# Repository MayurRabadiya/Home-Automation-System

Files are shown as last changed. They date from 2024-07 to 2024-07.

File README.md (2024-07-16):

# Home Automation System
## What is Home Automation?
Home automation, often referred to as smart home technology, involves the automation of household activities through various control systems. This includes the monitoring and control of home attributes such as lighting, climate, entertainment systems, and appliances. Additionally, home automation encompasses security features like access control and alarm systems. When connected to the Internet, these devices become integral components of the Internet of Things (IoT).

## Project Aim
The objective of our Smart Module is to provide a comprehensive solution for controlling home electronic appliances using a smartphone, touch control, IR remote, and voice assistants like Alexa and Google Assistant.

## Modes of Operation
1. Touch Control: Utilizes a Cypress capacitive touch sensor to detect user touch inputs and respond based on the previous state of the relay.

2. Voice Command: Voice commands are facilitated through Alexa, which publishes MQTT messages. The ESP8266 module subscribes to these topics to receive the messages. Communication between the Cypress chip and ESP8266 occurs via I2C, enabling the system to react appropriately.

3. IR Remote: The ESP8266 decodes input from an IR remote and sends commands to the Cypress chip via I2C communication. The Cypress chip processes these commands to control the relays.

4. Smartphone: A smartphone app publishes MQTT messages that the ESP8266 module subscribes to. These messages are communicated to the Cypress chip through I2C, enabling the system to control the relays based on the received commands.

This project demonstrates the integration of various modern technologies to create a versatile and user-friendly home automation system.

## Images
Touch pad top side           |  Touch pad bottom side
:-------------------------:|:-------------------------:
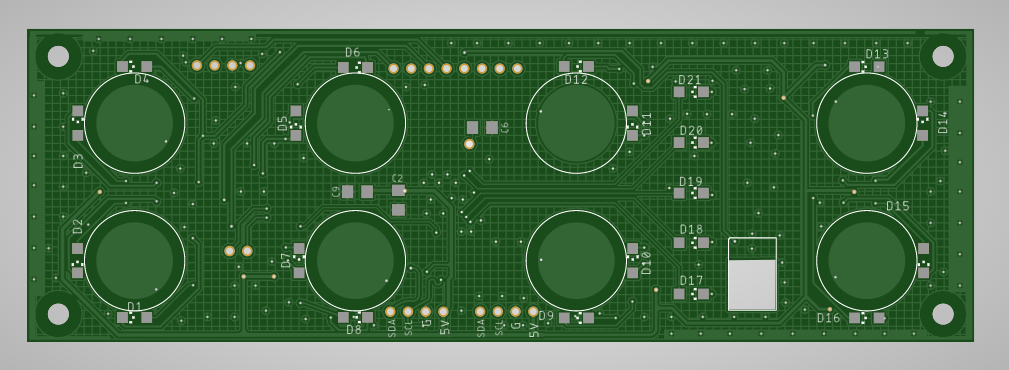
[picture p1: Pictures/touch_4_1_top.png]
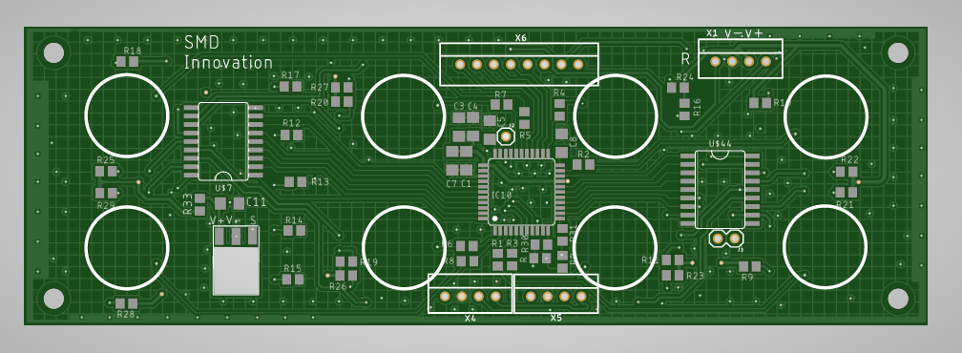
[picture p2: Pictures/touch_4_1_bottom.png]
  |  

Power base top side           |  Power base bottom side
:-------------------------:|:-------------------------:
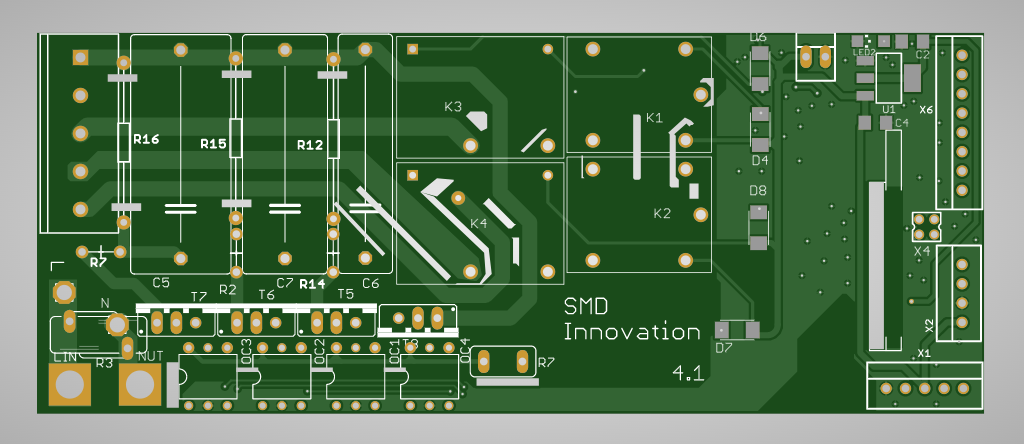
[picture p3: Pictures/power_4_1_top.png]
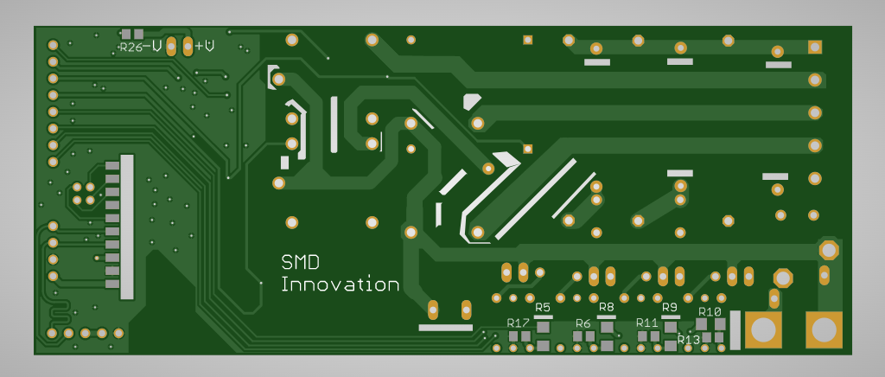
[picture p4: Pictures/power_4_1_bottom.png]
  |  

Front Cover      
| :-------------------------:|
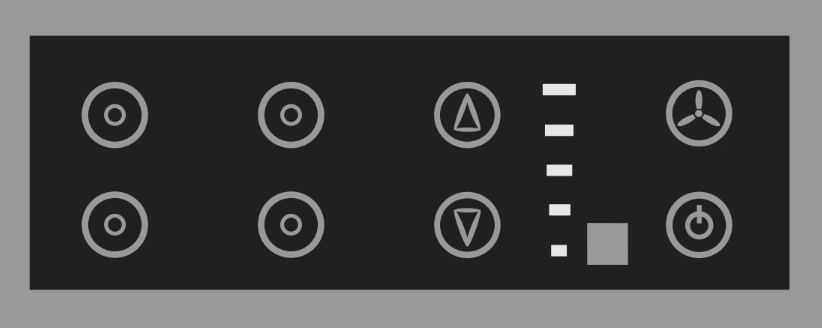
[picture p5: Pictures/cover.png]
|   |

Demo

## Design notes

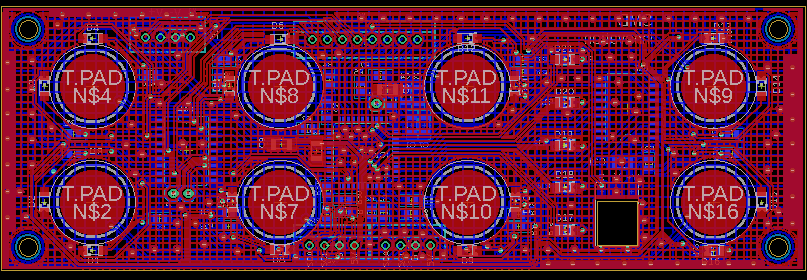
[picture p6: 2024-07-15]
4.1/4.1_TOUCH/pictures/4.1_top.png

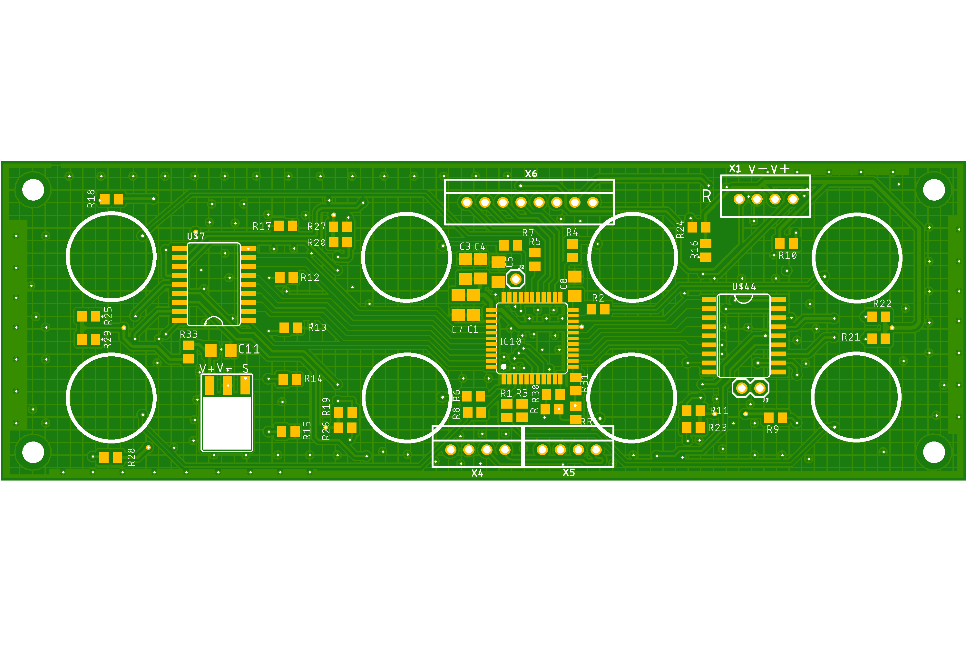
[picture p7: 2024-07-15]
4.1/4.1_TOUCH/pictures/6_light_1_fan_1.png

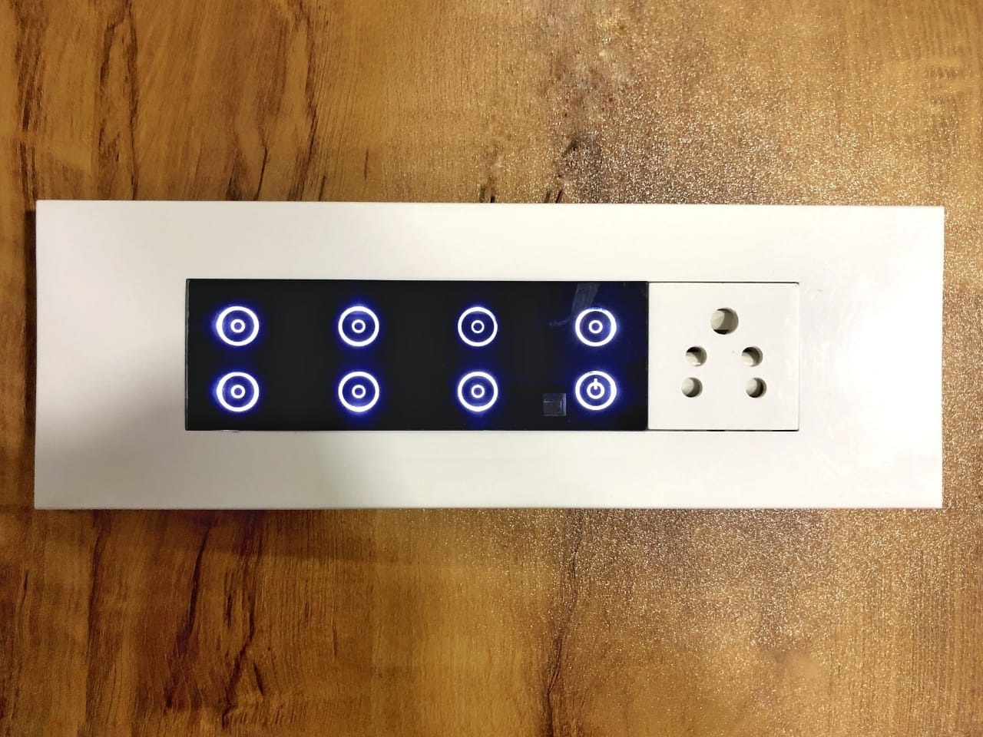
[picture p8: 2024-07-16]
Pictures/Touch Panel.png

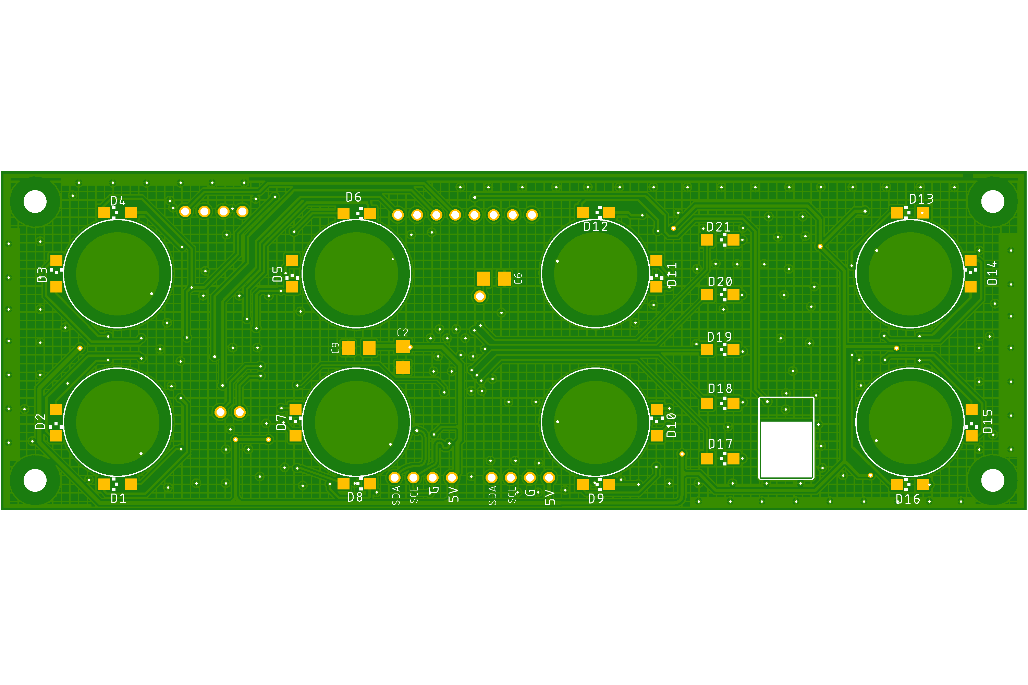
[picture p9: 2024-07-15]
4.1/4.1_TOUCH/pictures/6_light_1_fan_0.png

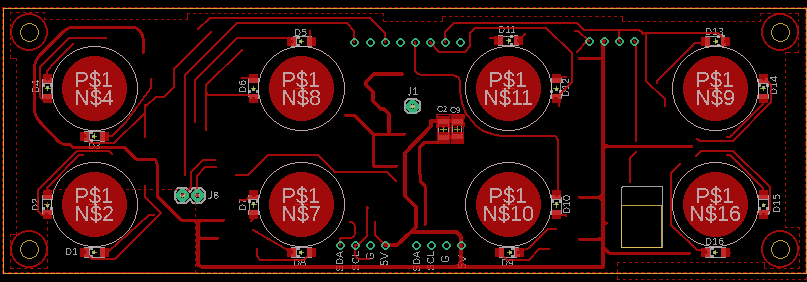
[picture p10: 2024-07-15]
7.0/7.0_TOUCH/pictures/7.0_top.png

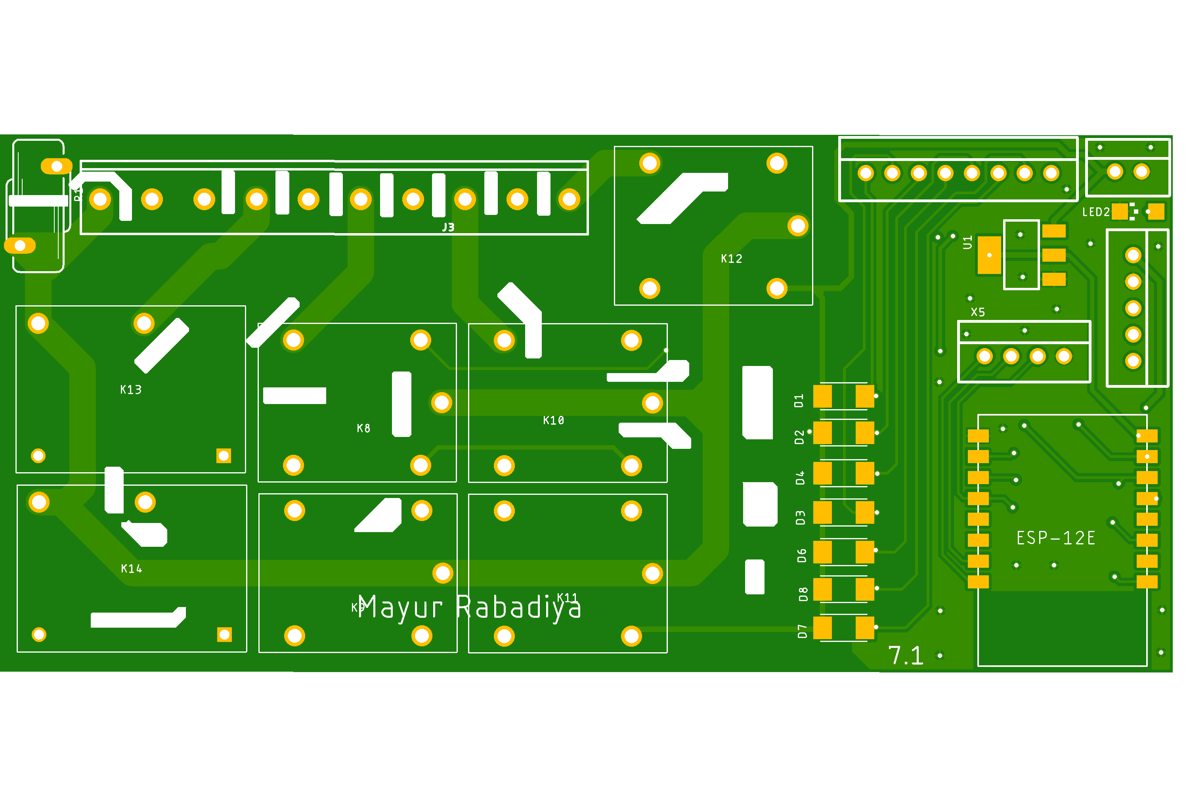
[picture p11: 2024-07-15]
7.0/7.0_POWER/pictures/6_light_1_fan_base_0.png

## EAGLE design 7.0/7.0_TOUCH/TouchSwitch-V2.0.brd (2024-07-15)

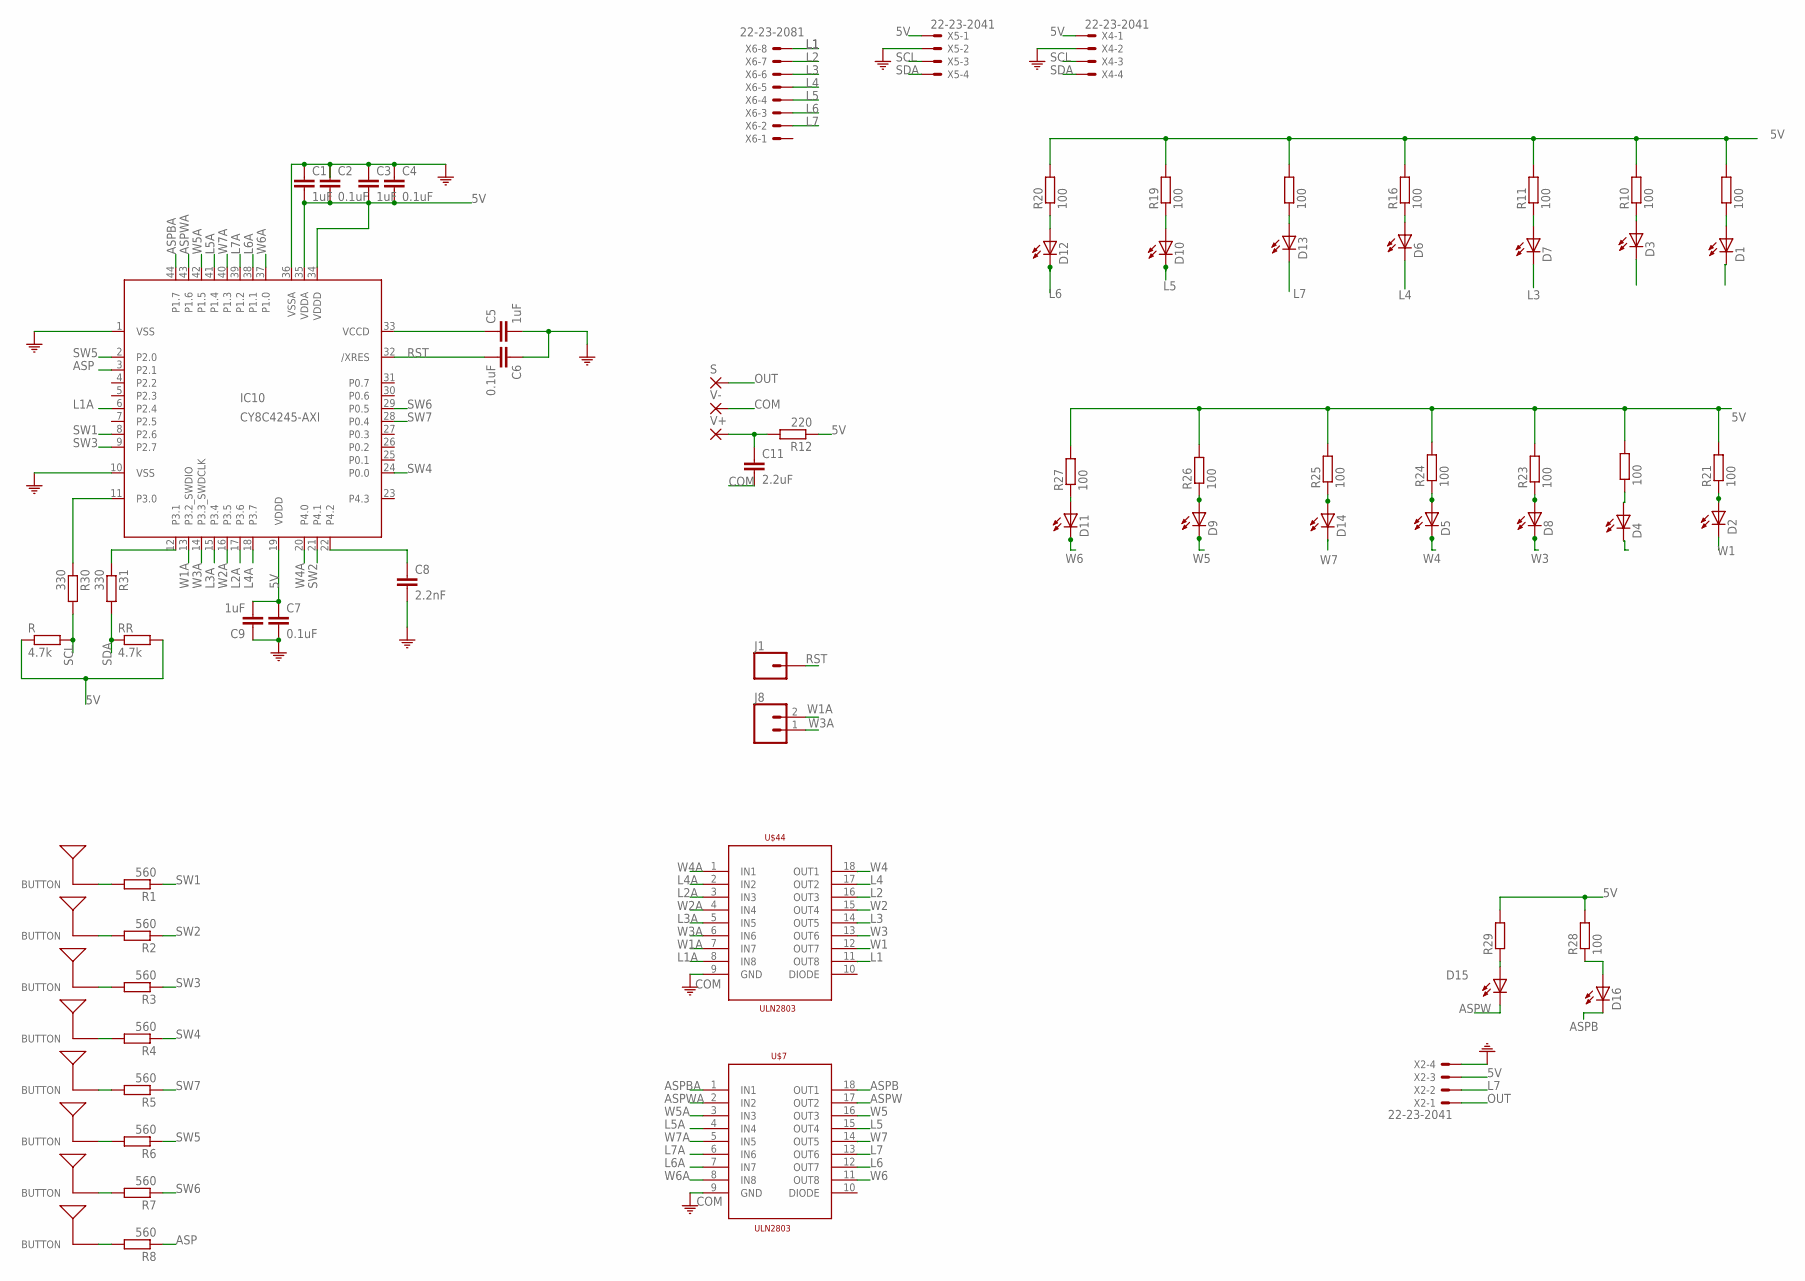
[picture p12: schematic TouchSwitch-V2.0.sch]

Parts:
B1, B2, B3, B4, B5, B6, B7, B8: BUTTON_PASSIVE12MM; BUTTON_PASSIVE_12MM
C1, C3, C5, C9: 1uF; C1206
C2, C4, C6, C7: 0.1uF; C1206
C8: 2.2nF; C1206
C11: 2.2uF; C1206
D1, D2, D3, D4, D5, D6, D7, D8, D9, D10, D11, D12, D13, D14, D15, D16: LEDCHIPLED_1206; CHIPLED_1206
IC10: CY8C4245-AXI; 44-TQFP-0.8
J1: CONN_01; 1X01
J8: CONN_02; 1X02
R: 4.7k; R0805
R1, R2, R3, R4, R5, R6, R7, R8: 560; R0805
R9, R10, R11, R16, R18, R19, R20, R21, R22, R23, R24, R25, R26, R27, R28, R29: 100; R0805
R12: 220; R0805
R30, R31: 330; R0805
RR: 4.7k; R0805
S: SMD2; SMD1,27-2,54
U$7, U$44: ULN2803; SO18L
V+: SMD2; SMD1,27-2,54
V-: SMD2; SMD1,27-2,54
X2, X4, X5: 22-23-2041
X6: 22-23-2081

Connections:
5V: C1.2, C2.2, C3.2, C4.2, C7.1, C9.2, IC10.19 (VDDD), IC10.34 (VDDD), IC10.35 (VDDA), R.1, R9.2, R10.2, R11.2, R12.1, R16.2, R18.2, R19.2, R20.2, R21.2, R22.2, R23.2, R24.2, R25.2, R26.2, R27.2, R28.2, R29.2, RR.2, X2.3, X4.1, X5.1
ASP: IC10.3 (P2.1), R8.1
ASPB: D16.C, U$7.18 (OUT1)
ASPBA: IC10.44 (P1.7), U$7.1 (IN1)
ASPW: D15.C, U$7.17 (OUT2)
ASPWA: IC10.43 (P1.6), U$7.2 (IN2)
COM: C1.1, C2.1, C3.1, C4.1, C5.2, C6.1, C7.2, C8.2, C9.1, C11.2, IC10.1 (VSS), IC10.10 (VSS), IC10.36 (VSSA), U$7.9 (GND), U$44.9 (GND), V-.1, X2.4, X4.2, X5.2
L1: D1.C, U$44.11 (OUT8), X6.8
L1A: IC10.6 (P2.4), U$44.8 (IN8)
L2: D3.C, U$44.16 (OUT3), X6.7
L2A: IC10.17 (P3.6), U$44.3 (IN3)
L3: D7.C, U$44.14 (OUT5), X6.6
L3A: IC10.15 (P3.4), U$44.5 (IN5)
L4: D6.C, U$44.17 (OUT2), X6.5
L4A: IC10.18 (P3.7), U$44.2 (IN2)
L5: D10.C, U$7.15 (OUT4), X6.4
L5A: IC10.41 (P1.4), U$7.4 (IN4)
L6: D12.C, U$7.12 (OUT7), X6.3
L6A: IC10.38 (P1.1), U$7.7 (IN7)
L7: D13.C, U$7.13 (OUT6), X2.2, X6.2
L7A: IC10.39 (P1.2), U$7.6 (IN6)
unnamed: C8.1, IC10.22 (P4.2)
unnamed: B8.P$1, R1.2
unnamed: IC10.11 (P3.0), R30.1
unnamed: B1.P$1, R2.2
unnamed: IC10.12 (P3.1), R31.1
unnamed: D10.A, R19.1
unnamed: B2.P$1, R3.2
unnamed: B3.P$1, R4.2
unnamed: B4.P$1, R5.2
unnamed: B5.P$1, R6.2
unnamed: B6.P$1, R7.2
unnamed: D13.A, R18.1
unnamed: C11.1, R12.2, V+.1
unnamed: D12.A, R20.1
unnamed: D6.A, R16.1
unnamed: B7.P$1, R8.2
unnamed: D7.A, R11.1
unnamed: D15.A, R29.1
unnamed: D3.A, R10.1
unnamed: D1.A, R9.1
unnamed: D5.A, R24.1
unnamed: D11.A, R27.1
unnamed: D9.A, R26.1
unnamed: D14.A, R25.1
unnamed: D2.A, R21.1
unnamed: D4.A, R22.1
unnamed: D8.A, R23.1
unnamed: D16.A, R28.1
unnamed: C5.1, IC10.33 (VCCD)
OUT: S.1, X2.1
RST: C6.2, IC10.32 (/XRES), J1.1
SCL: R.2, R30.2, X4.3, X5.3
SDA: R31.2, RR.1, X4.4, X5.4
SW1: IC10.8 (P2.6), R1.1
SW2: IC10.21 (P4.1), R2.1
SW3: IC10.9 (P2.7), R3.1
SW4: IC10.24 (P0.0), R4.1
SW5: IC10.2 (P2.0), R6.1
SW6: IC10.29 (P0.5), R7.1
SW7: IC10.28 (P0.4), R5.1
W1: D2.C, U$44.12 (OUT7)
W1A: IC10.13 (P3.2_SWDIO), J8.2, U$44.7 (IN7)
W2: D4.C, U$44.15 (OUT4)
W2A: IC10.16 (P3.5), U$44.4 (IN4)
W3: D8.C, U$44.13 (OUT6)
W3A: IC10.14 (P3.3_SWDCLK), J8.1, U$44.6 (IN6)
W4: D5.C, U$44.18 (OUT1)
W4A: IC10.20 (P4.0), U$44.1 (IN1)
W5: D9.C, U$7.16 (OUT3)
W5A: IC10.42 (P1.5), U$7.3 (IN3)
W6: D11.C, U$7.11 (OUT8)
W6A: IC10.37 (P1.0), U$7.8 (IN8)
W7: D14.C, U$7.14 (OUT5)
W7A: IC10.40 (P1.3), U$7.5 (IN5)

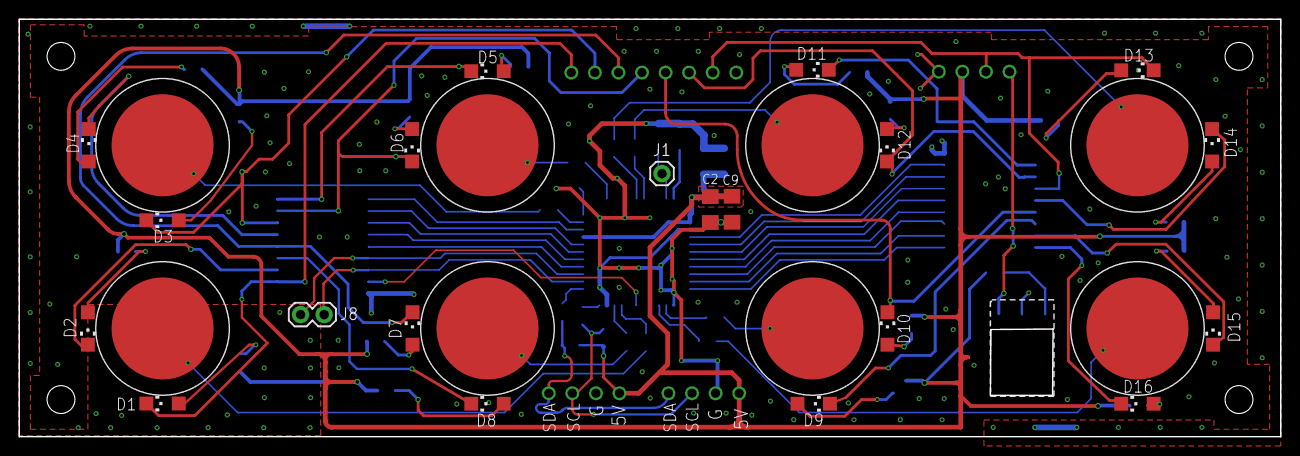
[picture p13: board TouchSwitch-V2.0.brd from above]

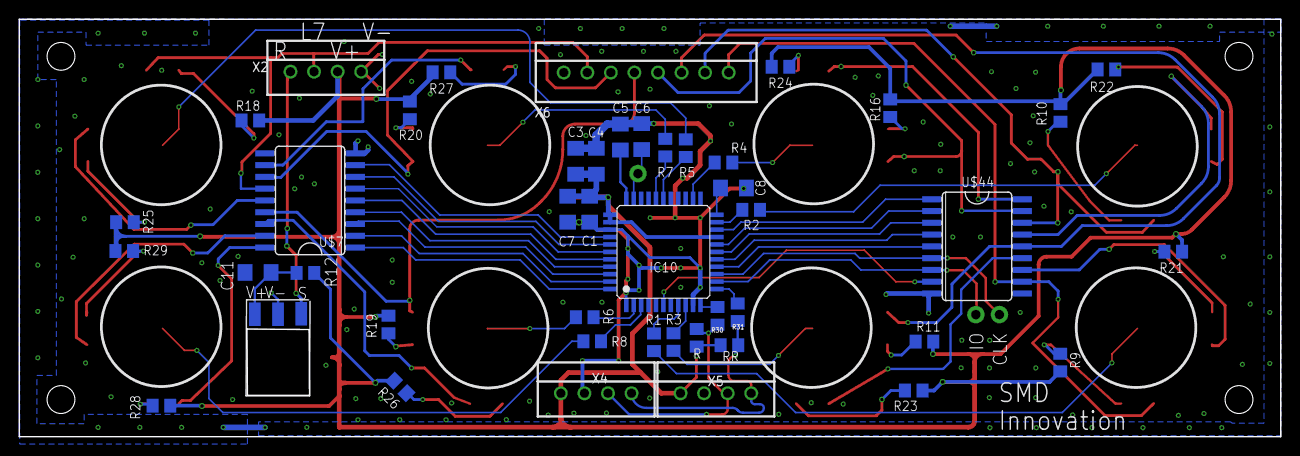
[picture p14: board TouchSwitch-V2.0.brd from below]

Board: 2 copper layers, 136.0 x 45.0 mm, 75 parts (47 on the bottom side), 75 nets.

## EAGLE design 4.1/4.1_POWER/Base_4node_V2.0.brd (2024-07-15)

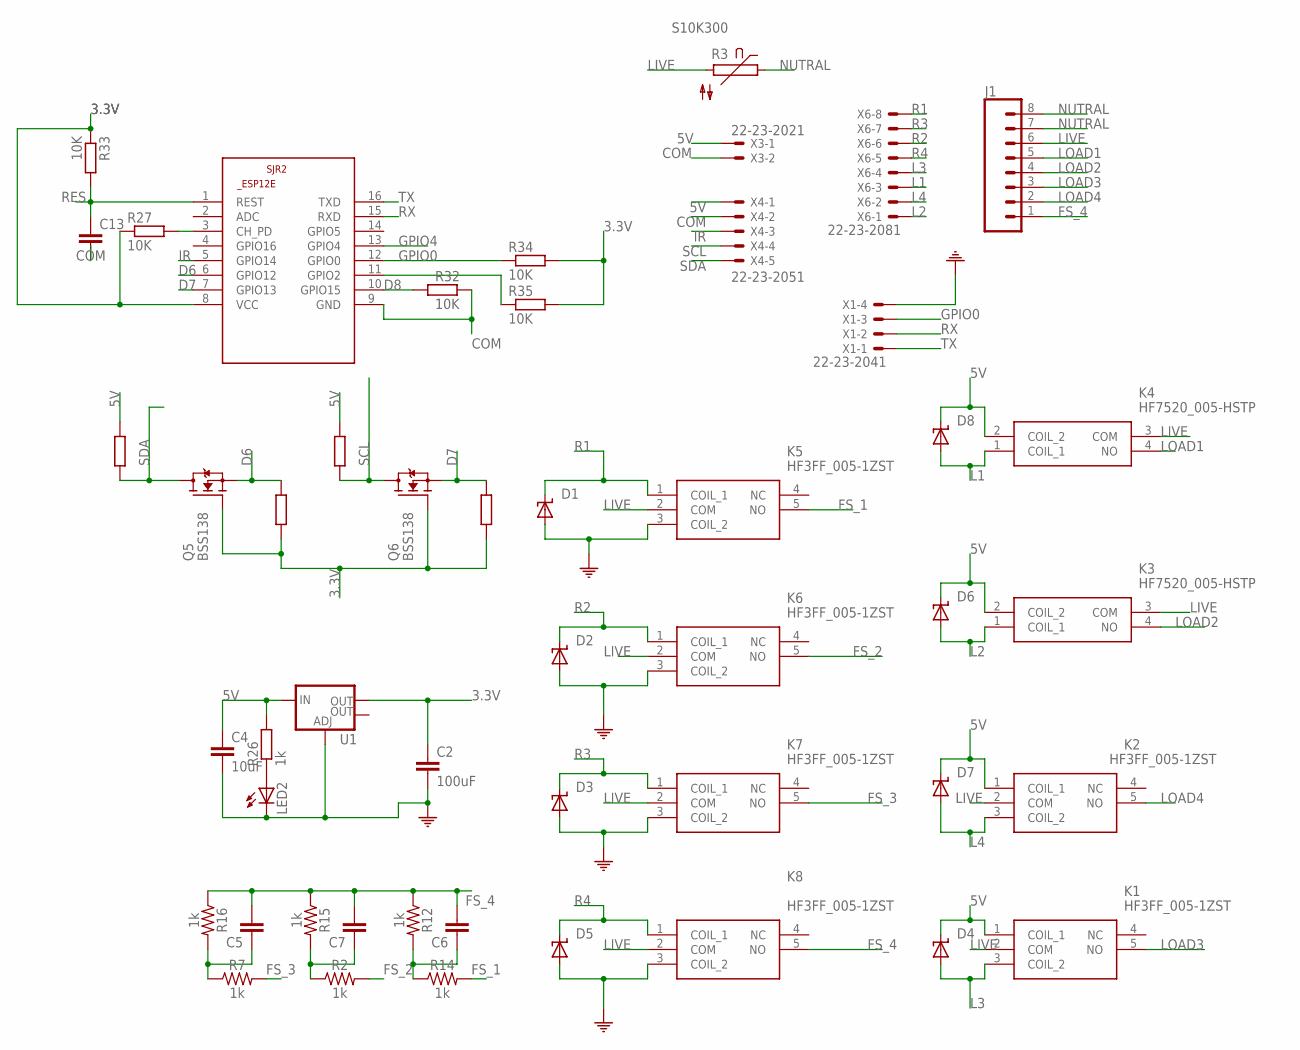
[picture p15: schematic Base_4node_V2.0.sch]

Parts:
C2: 100uF; C1206
C4: 10uF; C1206
C5: C-EU275-134X316; C275-134X316
C6: C-EU275-093X316; C275-093X316
C7: C-EU275-113X316; C275-113X316
C13: C-EUC0805; C0805
D1, D2, D3, D4, D5, D6, D7, D8: SUPPRESSOR-SMBJ; SMBJ
J1: CONN_083.5MM-8; SCREWTERMINAL-3.5MM-8
K1, K2, K5, K6, K7, K8: HF3FF_005-1ZST; HF3FF0051ZST
K3, K4: HF7520_005-HSTP; HF7520005HSTP
LED2: LEDCHIPLED_1206; CHIPLED_1206
Q5, Q6: BSS138; SOT23
R2, R7, R14: 1k; AXIAL-0.1
R3: S10K300
R12, R15, R16: 1k; AXIAL-0.3
R26: 1k; R0805
R27, R32, R33, R34, R35, R36, R37, R38, R39: 10K; R0805
SJR2: ESP8266-12EESP12E; ESP8266-ESP12E
U1: V_REG_LM1117SOT223; SOT223
X1: 22-23-2041
X3: 22-23-2021
X4: 22-23-2051
X6: 22-23-2081

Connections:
3.3V: C2.1, Q5.1 (G), Q6.1 (G), R27.1, R33.1, R34.2, R35.2, R37.2, R39.2, SJR2.8 (VCC), U1.2 (OUT)
5V: C4.1, D4.C, D6.C, D7.C, D8.C, K1.1 (COIL_1), K2.1 (COIL_1), K3.2 (COIL_2), K4.2 (COIL_2), R26.2, R36.2, R38.2, U1.3 (IN), X3.1, X4.1
COM: C2.2, C4.2, C13.2, D1.A, D2.A, D3.A, D5.A, K5.3 (COIL_2), K6.3 (COIL_2), K7.3 (COIL_2), K8.3 (COIL_2), LED2.C, R32.2, SJR2.9 (GND), U1.1 (ADJ), X1.4, X3.2, X4.2
D6: Q5.2 (S), R37.1, SJR2.6 (GPIO12)
D7: Q6.2 (S), R39.1, SJR2.7 (GPIO13)
D8: R32.1, SJR2.10 (GPIO15)
FS_1: K5.5 (NO), R14.P$2 (2)
FS_2: K6.5 (NO), R2.P$2 (2)
FS_3: K7.5 (NO), R7.P$2 (2)
FS_4: C5.2, C6.2, C7.2, J1.1, K8.5 (NO), R12.P$1 (1), R15.P$1 (1), R16.P$1 (1)
GPIO0: R34.1, SJR2.12 (GPIO0), X1.3
GPIO4: SJR2.13 (GPIO4)
IR: SJR2.5 (GPIO14), X4.3
L1: D8.A, K4.1 (COIL_1), X6.3
L2: D6.A, K3.1 (COIL_1), X6.1
L3: D4.A, K1.3 (COIL_2), X6.4
L4: D7.A, K2.3 (COIL_2), X6.2
LIVE: J1.6, K1.2 (COM), K2.2 (COM), K3.3 (COM), K4.3 (COM), K5.2 (COM), K6.2 (COM), K7.2 (COM), K8.2 (COM), R3.2
LOAD1: J1.5, K4.4 (NO)
LOAD2: J1.4, K3.4 (NO)
LOAD3: J1.3, K1.5 (NO)
LOAD4: J1.2, K2.5 (NO)
unnamed: C6.1, R12.P$2 (2), R14.P$1 (1)
unnamed: C7.1, R2.P$1 (1), R15.P$2 (2)
unnamed: C5.1, R7.P$1 (1), R16.P$2 (2)
unnamed: LED2.A, R26.1
unnamed: R35.1, SJR2.11 (GPIO2)
unnamed: R27.2, SJR2.3 (CH_PD)
NUTRAL: J1.7, J1.8, R3.1
R1: D1.C, K5.1 (COIL_1), X6.8
R2: D2.C, K6.1 (COIL_1), X6.6
R3: D3.C, K7.1 (COIL_1), X6.7
R4: D5.C, K8.1 (COIL_1), X6.5
RES: C13.1, R33.2, SJR2.1 (REST)
RX: SJR2.15 (RXD), X1.2
SCL: Q6.3 (D), R36.1, X4.4
SDA: Q5.3 (D), R38.1, X4.5
TX: SJR2.16 (TXD), X1.1

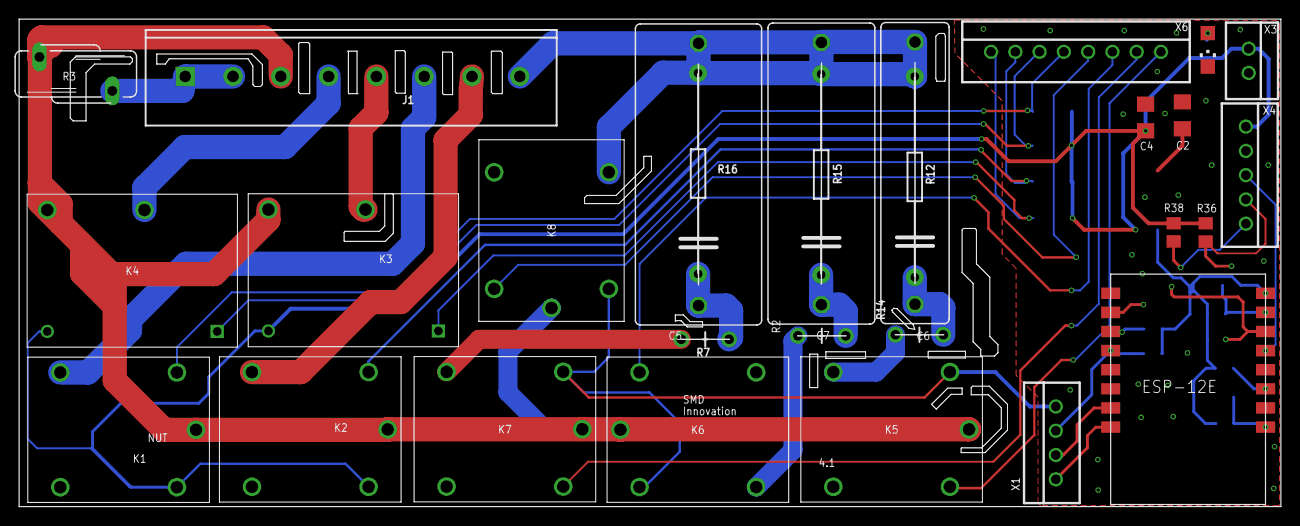
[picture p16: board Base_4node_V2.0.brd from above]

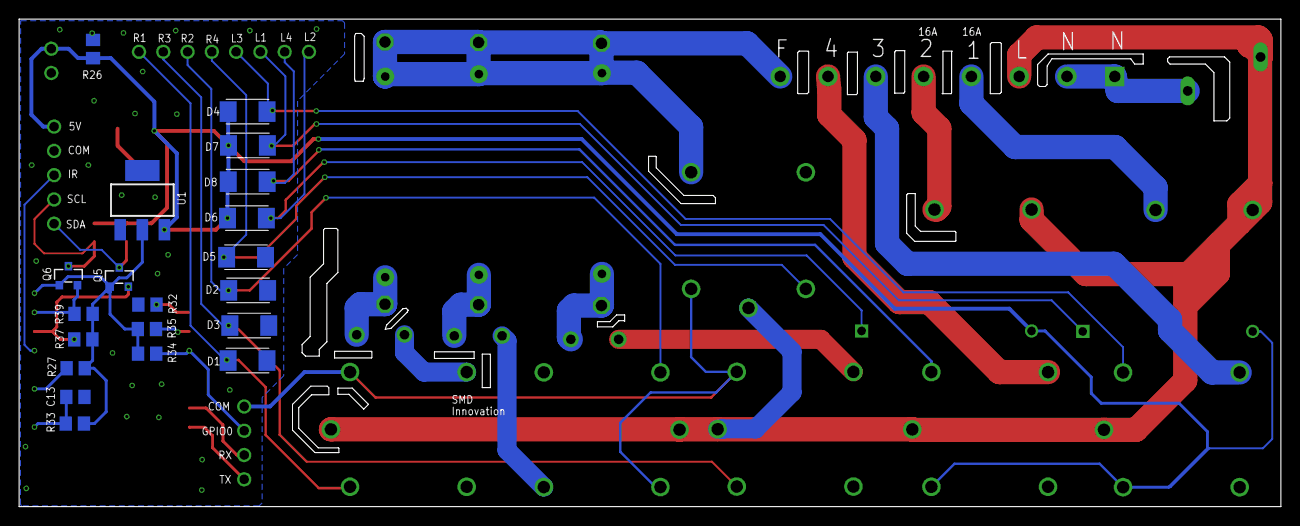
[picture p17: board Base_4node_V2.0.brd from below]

Board: 2 copper layers, 132.0 x 51.0 mm, 49 parts (20 on the bottom side), 37 nets.

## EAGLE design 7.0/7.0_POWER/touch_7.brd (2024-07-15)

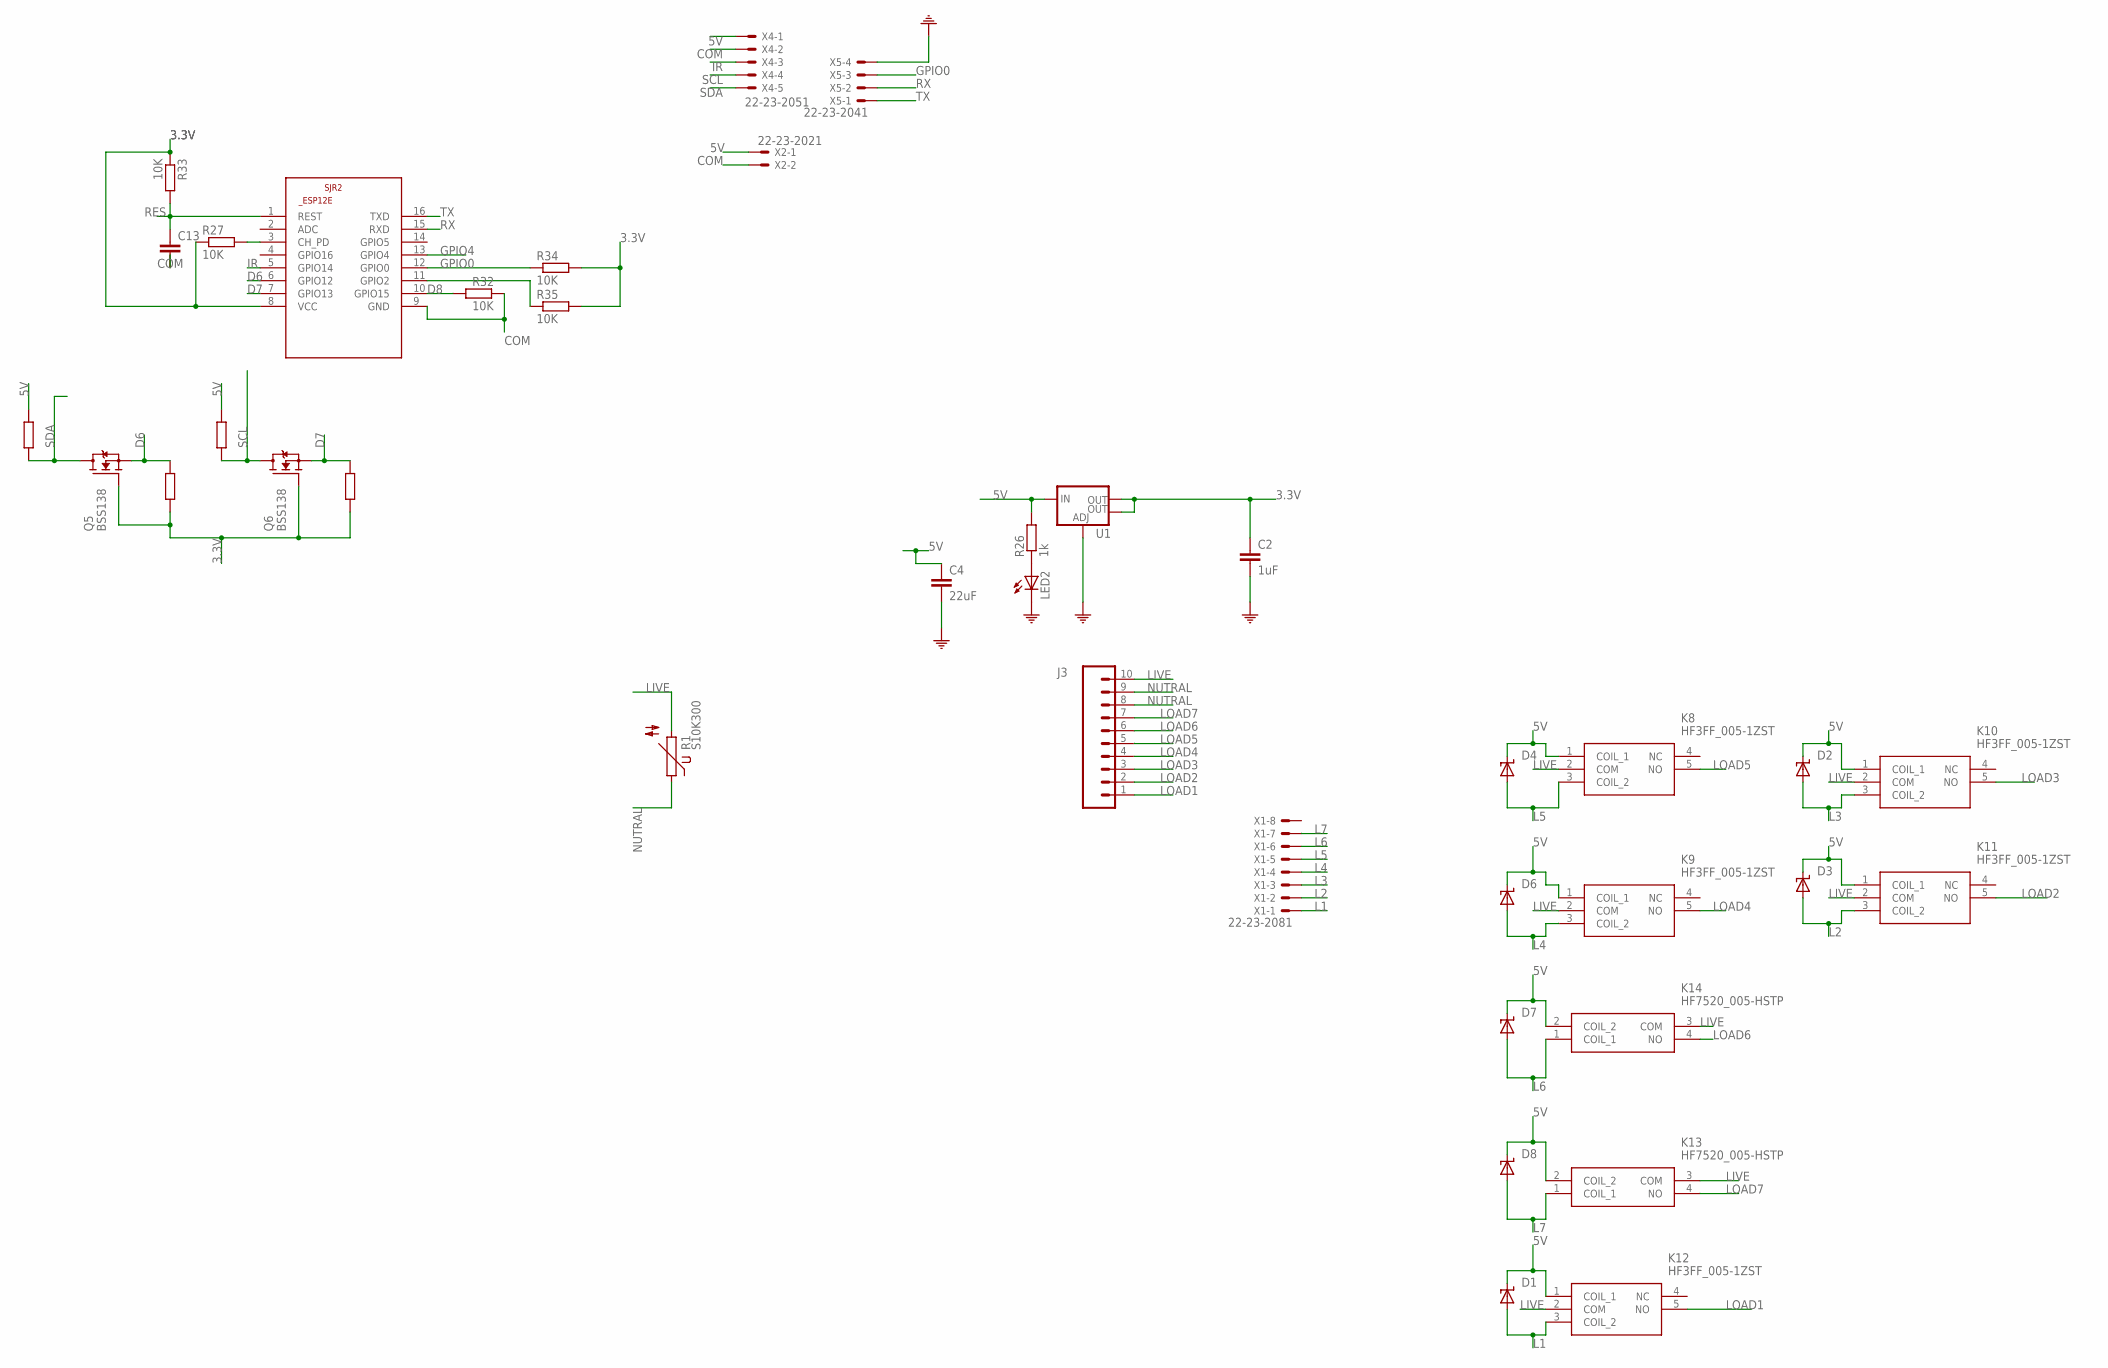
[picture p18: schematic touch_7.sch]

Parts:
C2: 1uF; C1206
C4: 22uF; C1206
C13: C-EUC0805; C0805
D1, D2, D3, D4, D6, D7, D8: SUPPRESSOR-SMBJ; SMBJ
J3: CONN_083.5MM-8; SCREWTERMINAL-3.5MM-8
K8, K9, K10, K11, K12: HF3FF_005-1ZST; HF3FF0051ZST
K13, K14: HF7520_005-HSTP; HF7520005HSTP
LED2: LEDCHIPLED_1206; CHIPLED_1206
Q5, Q6: BSS138; SOT23
R1: S10K300
R26: 1k; R0805
R27, R32, R33, R34, R35, R36, R37, R38, R39: 10K; R0805
SJR2: ESP8266-12EESP12E; ESP8266-ESP12E
U1: V_REG_LM1117SOT223; SOT223
X1: 22-23-2081
X2: 22-23-2021
X4: 22-23-2051
X5: 22-23-2041

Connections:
3.3V: C2.1, Q5.1 (G), Q6.1 (G), R27.1, R33.1, R34.2, R35.2, R37.2, R39.2, SJR2.8 (VCC), U1.2 (OUT), U1.4 (OUT)
5V: C4.1, D1.C, D2.C, D3.C, D4.C, D6.C, D7.C, D8.C, K8.1 (COIL_1), K9.1 (COIL_1), K10.1 (COIL_1), K11.1 (COIL_1), K12.1 (COIL_1), K13.2 (COIL_2), K14.2 (COIL_2), R26.2, R36.2, R38.2, U1.3 (IN), X2.1, X4.1
COM: C2.2, C4.2, C13.2, LED2.C, R32.2, SJR2.9 (GND), U1.1 (ADJ), X2.2, X4.2, X5.4
D6: Q5.2 (S), R37.1, SJR2.6 (GPIO12)
D7: Q6.2 (S), R39.1, SJR2.7 (GPIO13)
D8: R32.1, SJR2.10 (GPIO15)
GPIO0: R34.1, SJR2.12 (GPIO0), X5.3
GPIO4: SJR2.13 (GPIO4)
IR: SJR2.5 (GPIO14), X4.3
L1: D1.A, K12.3 (COIL_2), X1.1
L2: D3.A, K11.3 (COIL_2), X1.2
L3: D2.A, K10.3 (COIL_2), X1.3
L4: D6.A, K9.3 (COIL_2), X1.4
L5: D4.A, K8.3 (COIL_2), X1.5
L6: D7.A, K14.1 (COIL_1), X1.6
L7: D8.A, K13.1 (COIL_1), X1.7
LIVE: J3.10, K8.2 (COM), K9.2 (COM), K10.2 (COM), K11.2 (COM), K12.2 (COM), K13.3 (COM), K14.3 (COM), R1.2
LOAD1: J3.1, K12.5 (NO)
LOAD2: J3.2, K11.5 (NO)
LOAD3: J3.3, K10.5 (NO)
LOAD4: J3.4, K9.5 (NO)
LOAD5: J3.5, K8.5 (NO)
LOAD6: J3.6, K14.4 (NO)
LOAD7: J3.7, K13.4 (NO)
unnamed: LED2.A, R26.1
unnamed: R35.1, SJR2.11 (GPIO2)
unnamed: R27.2, SJR2.3 (CH_PD)
NUTRAL: J3.8, J3.9, R1.1
RES: C13.1, R33.2, SJR2.1 (REST)
RX: SJR2.15 (RXD), X5.2
SCL: Q6.3 (D), R36.1, X4.4
SDA: Q5.3 (D), R38.1, X4.5
TX: SJR2.16 (TXD), X5.1

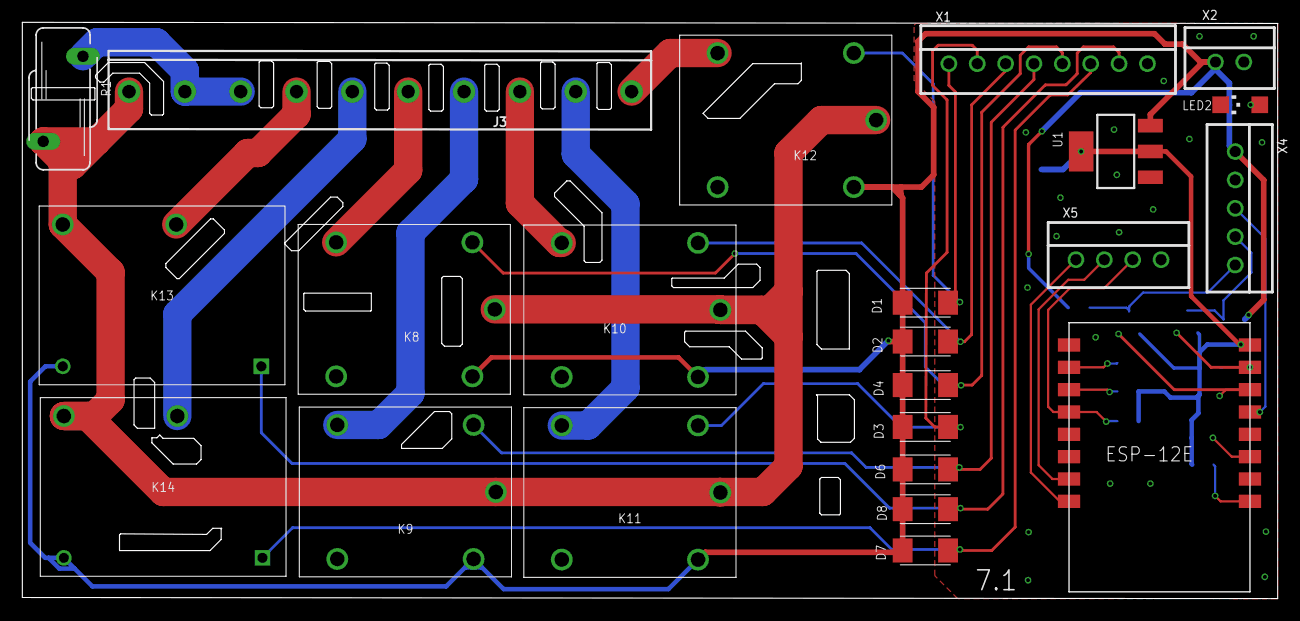
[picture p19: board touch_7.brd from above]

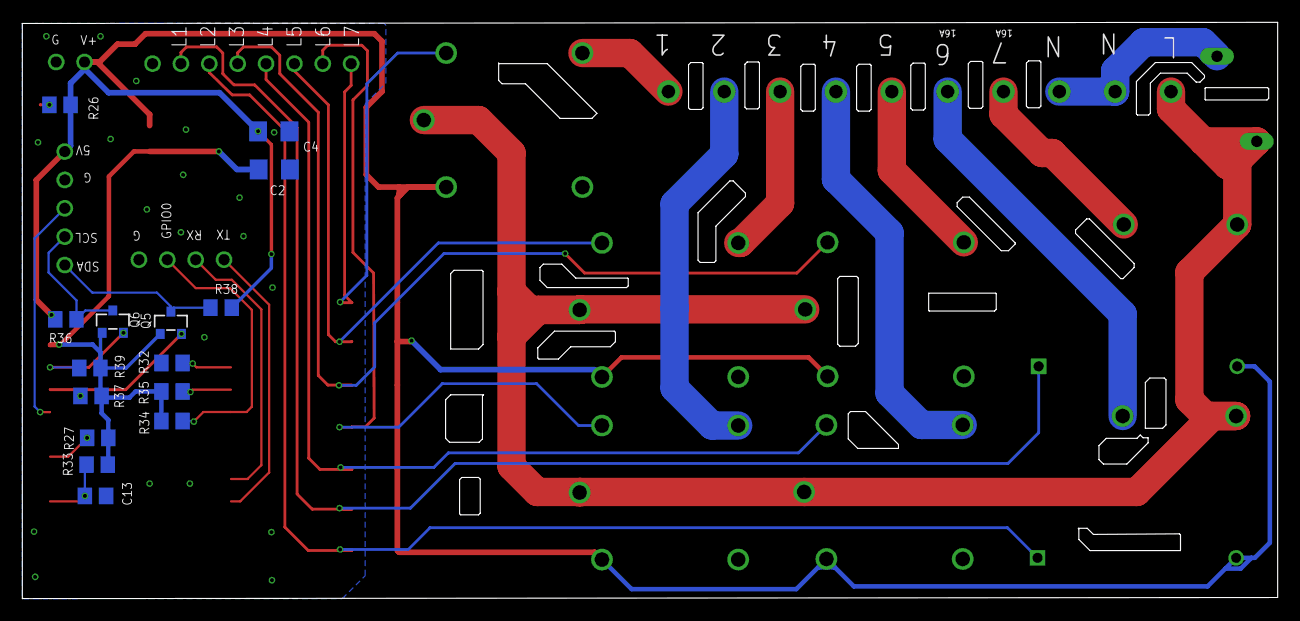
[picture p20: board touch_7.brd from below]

Board: 2 copper layers, 112.4 x 51.6 mm, 38 parts (15 on the bottom side), 32 nets.

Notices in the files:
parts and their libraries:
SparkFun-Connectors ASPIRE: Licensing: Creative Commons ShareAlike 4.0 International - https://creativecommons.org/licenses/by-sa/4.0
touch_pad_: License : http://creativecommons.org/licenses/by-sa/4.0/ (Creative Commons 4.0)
